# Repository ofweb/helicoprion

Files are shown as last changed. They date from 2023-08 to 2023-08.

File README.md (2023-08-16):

# Helicoprion Keyboard

The Helicoprion Keyboard is a 44-key diodeless, flippable, choc spaced, hotswap, aggressive column staggered, split keyboard powered by Pro Micro pin compatible board, eg a nice!nano or a KB2040.
It does not have battery support, but you can use a nice!nano wired if you want.

I made this after having build and attempted to use a sweep. Tha lack of dedicated modifier keys kept being a problem for me. The normal tucky thumb keys are hard to reach for me so I came up with this that I think feels better.
I don't expect this to by my last iteration on a keyboard so it is made to allow me to recycle the MCU and the switches in a next iteration.

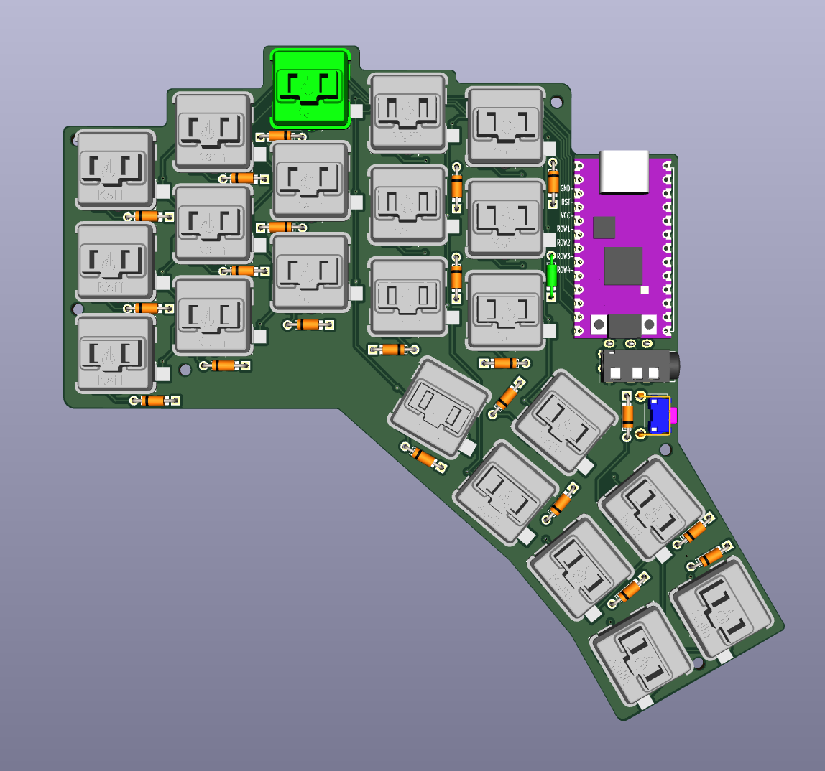
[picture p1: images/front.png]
left

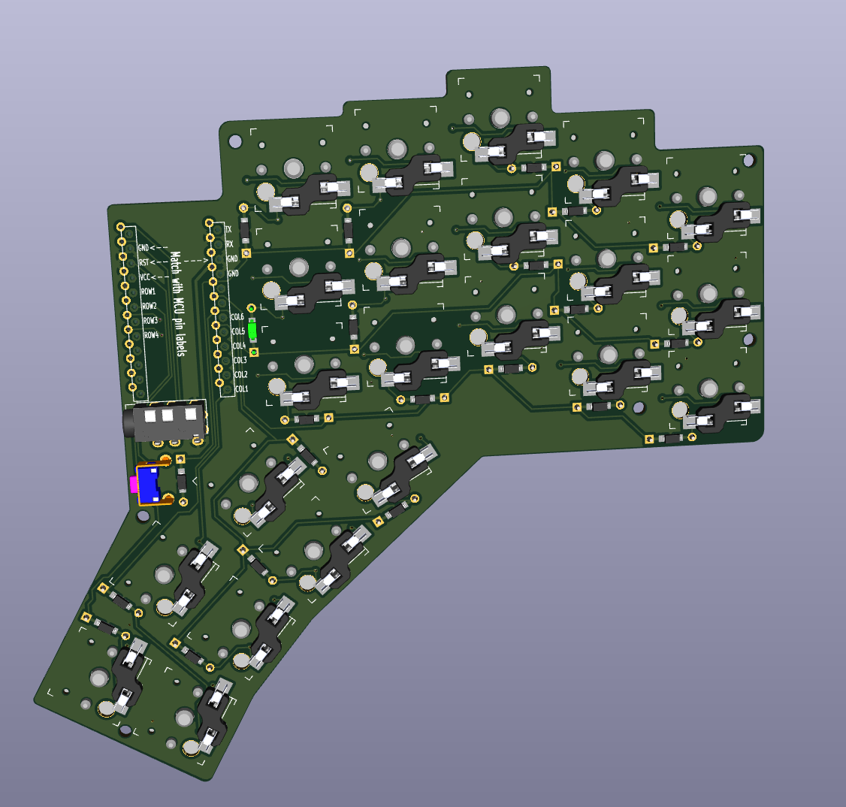
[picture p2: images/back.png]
right


# Testing
If you want to see if this is right for you you can start with printing a paper tester (TODO). If you have access to a 3d-printer you can print the step file(TODO) from the repo and add you switches, this should give you a better indication on if it is right.

# Inspiration

* [Sweep](https://github.com/davidphilipbarr/Sweep) The main inspiration is from the ferris sweep I started trying to used I needed more keys.
* [Hillside](https://github.com/mmccoyd/hillside) The very pretty promicro foot print and how to wire it.
* [Torn](https://github.com/rtitmuss/torn) For not be afraid of showing the components and that it can look very nice.

## Features

* Pro Micro MCU - Many options
* Sweep inspired layout - Ergonomic strong column staggering for short pinkies.
* Flippable PCBs - Cheaper to order the PCBs
* Hotswap low profile choc switches - Experiment with different key switches with the hotswap sockets.
* Very large thumb cluster - Let your thumb do more of the work.
* Both SMD and THT diodes - Pick if you want the easier to solder or the smaller diodes.

## Bill of Materials (BOM)

[Interactive](https://ofweb.github.io/helicoprion/)

Quantity | Item
--- | ---
2 | Helicoprion PCB
2 | Pro Micro pin compatable comtrollers
44 | Kailh choc v1 PG1350 switches
44 | Choc v1 keycaps
44 | Kahli hotswap sockets for choc v1 PG1350
44 | Diodes both through-hole (eg. 1N4148) and smd (SOD-123) are supported
2 | TRRS jack PJ-320A (not needed for nice!nano)
1 | 3.5mm TRRS cable (not needed for nice!nano)
4 | Pin headers (20 pin) or sockets
2 | Reset Button (optional) ALPS SKHLLCA010 or footprint compatible

# releases
## V1
### Errata: 
 - sw9 connect pin 1 (square) to MCU pin 20 (row1)
 - sw10 connect pin 1 (square) to MCU pin 19 (row2)
 - MCU pin 10 to (col3) to MCU pin 10 (col3). The inner most pin is connected the outer most is not and need to be if you are using it.

# schematic
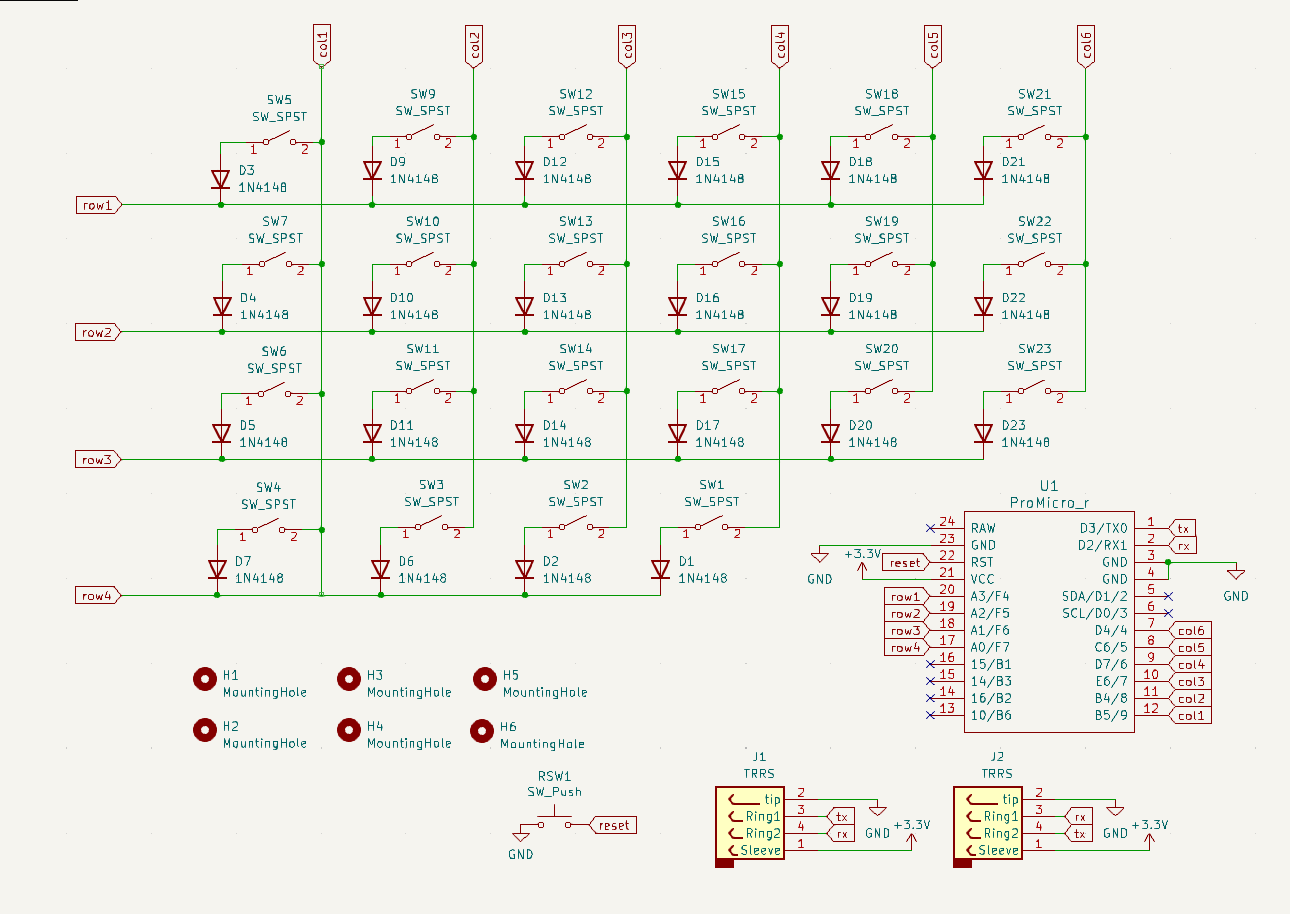
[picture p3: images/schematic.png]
schematic


## External footprints and symbols used

External symbols and footprints are not covered by the LICENSE in this repo.

* [Keebio-Parts.pretty](https://github.com/keebio/Keebio-Parts.pretty) is licensed under the MIT License.
* [keyswitches.pretty](https://github.com/daprice/keyswitches.pretty) is licensed under the Creative Commons Attribution-ShareAlike 4.0 International License.
* [Hillside](https://github.com/mmccoyd/hillside) is licensed under the MIT License.

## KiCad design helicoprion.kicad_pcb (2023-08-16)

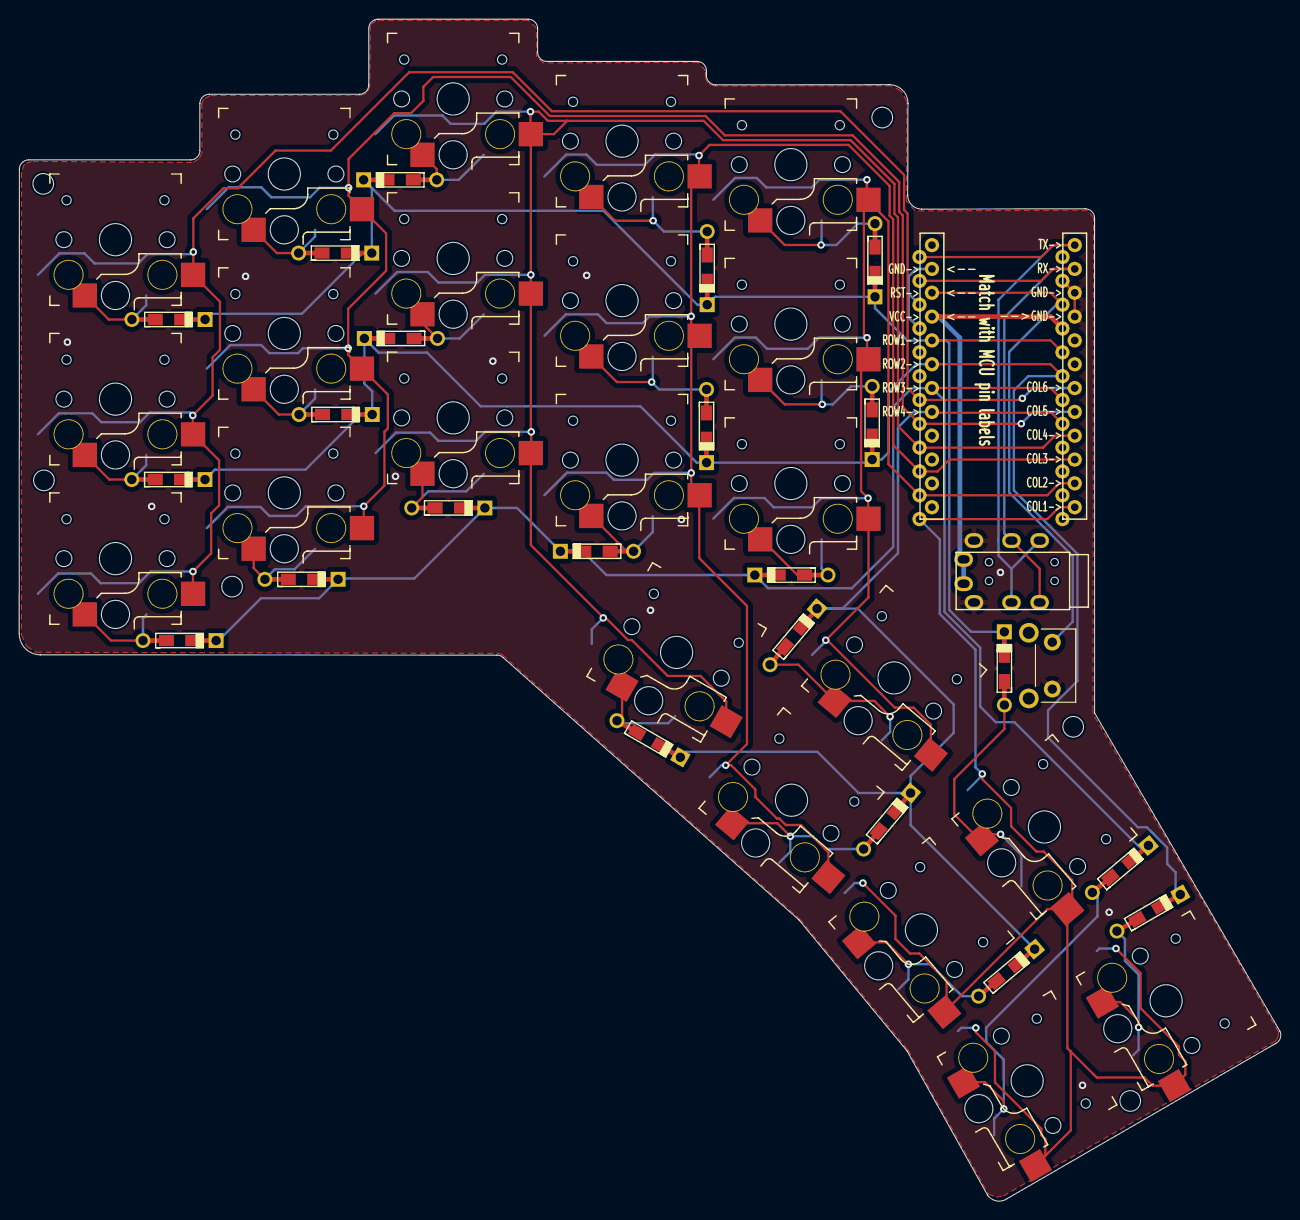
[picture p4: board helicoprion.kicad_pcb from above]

Board: 2 copper layers, 134.5 x 126.0 mm, 54 parts (1 on the bottom side), 37 nets.

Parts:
D1, D2, D3, D4, D5, D6, D7, D9, D10, D11, D12, D13, D14, D15, D16, D17, D18, D19, D20, D21, D22, D23: 1N4148; Diode-dual
H1, H2, H3, H4, H5, H6: MountingHole; MountingHole_2.2mm_M2
J1, J2: TRRS; TRRS-PJ-320A
RSW1: SW_Push; SW_SKHLLCA010
SW1, SW2, SW3, SW4, SW5, SW6, SW7, SW9, SW10, SW11, SW12, SW13, SW14, SW15, SW16, SW17, SW18, SW19, SW20, SW21, SW22, SW23: SW_SPST; Kailh_socket_PG1350_reversible
U1: ProMicro_r; ProMicro_v2

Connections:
+3.3V: J1.1 (Sleeve), J2.1 (Sleeve), U1.21 (VCC)
GND: J1.2 (tip), J2.2 (tip), RSW1.1, U1.3 (GND), U1.4 (GND), U1.23 (GND)
unnamed: D1.2 (A), SW1.1 (A)
unnamed: D2.2 (A), SW2.1 (A)
unnamed: D3.2 (A), SW5.1 (A)
unnamed: D4.2 (A), SW7.1 (A)
unnamed: D5.2 (A), SW6.1 (A)
unnamed: D6.2 (A), SW3.1 (A)
unnamed: D7.2 (A), SW4.1 (A)
unnamed: D9.2 (A), SW9.1 (A)
unnamed: D10.2 (A), SW10.1 (A)
unnamed: D11.2 (A), SW11.1 (A)
unnamed: D12.2 (A), SW12.1 (A)
unnamed: D13.2 (A), SW13.1 (A)
unnamed: D14.2 (A), SW14.1 (A)
unnamed: D15.2 (A), SW15.1 (A)
unnamed: D16.2 (A), SW16.1 (A)
unnamed: D17.2 (A), SW17.1 (A)
unnamed: D18.2 (A), SW18.1 (A)
unnamed: D19.2 (A), SW19.1 (A)
unnamed: D20.2 (A), SW20.1 (A)
unnamed: D21.2 (A), SW21.1 (A)
unnamed: D22.2 (A), SW22.1 (A)
unnamed: D23.2 (A), SW23.1 (A)
col1: SW4.2 (B), SW5.2 (B), SW6.2 (B), SW7.2 (B), U1.12 (B5/9)
col2: SW3.2 (B), SW9.2 (B), SW10.2 (B), SW11.2 (B), U1.11 (B4/8)
col3: SW2.2 (B), SW12.2 (B), SW13.2 (B), SW14.2 (B), U1.10 (E6/7)
col4: SW1.2 (B), SW15.2 (B), SW16.2 (B), SW17.2 (B), U1.9 (D7/6)
col5: SW18.2 (B), SW19.2 (B), SW20.2 (B), U1.8 (C6/5)
col6: SW21.2 (B), SW22.2 (B), SW23.2 (B), U1.7 (D4/4)
reset: RSW1.2, U1.22 (RST)
row1: D3.1 (K), D9.1 (K), D12.1 (K), D15.1 (K), D18.1 (K), D21.1 (K), U1.20 (A3/F4)
row2: D4.1 (K), D10.1 (K), D13.1 (K), D16.1 (K), D19.1 (K), D22.1 (K), U1.19 (A2/F5)
row3: D5.1 (K), D11.1 (K), D14.1 (K), D17.1 (K), D20.1 (K), D23.1 (K), U1.18 (A1/F6)
row4: D1.1 (K), D2.1 (K), D6.1 (K), D7.1 (K), U1.17 (A0/F7)
rx: J1.4 (Ring2), J2.3 (Ring1), U1.2 (D2/RX1)
tx: J1.3 (Ring1), J2.4 (Ring2), U1.1 (D3/TX0)

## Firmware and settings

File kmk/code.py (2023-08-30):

import board

from kmk.kmk_keyboard import KMKKeyboard
from kmk.keys import KC
from kmk.scanners import DiodeOrientation
from kmk.modules.split import Split, SplitType
from kmk.modules.layers import Layers
from kmk.modules.capsword import CapsWord
from kmk.extensions.media_keys import MediaKeys



keyboard = KMKKeyboard()
keyboard.debug_enabled = True
keyboard.modules.append(Layers())
keyboard.extensions.append(MediaKeys())

caps_word=CapsWord()
keyboard.modules.append(caps_word)

# https://github.com/KMKfw/kmk_firmware/blob/master/docs/en/split_keyboards.md
# https://github.com/KMKfw/kmk_firmware/blob/master/boards/kyria/main.py
split = Split(  
    split_side=None,
    split_type=SplitType.UART,
    uart_flip=False,
    data_pin=board.D1,
    data_pin2=board.D0,
    use_pio=False,
    split_target_left=True
)
keyboard.modules.append(split)

keyboard.col_pins = (board.D4, board.D5, board.D6, board.D7, board.D8, board.D9)
keyboard.row_pins = (board.A3, board.A2, board.A1, board.A0)
keyboard.diode_orientation = DiodeOrientation.COL2ROW


# +--+--+--+--+--+                    +--+--+--+--+--+
# |00|01|02|03|04|                    |28|27|26|25|24|
# +--+--+--+--+--+                    +--+--+--+--+--+
# |06|07|08|09|10|                    |34|33|32|31|30| 
# +--+--+--+--+--+                    +--+--+--+--+--+
# |12|13|14|15|16|                    |40|39|38|37|36|
# +--+--+--+--+--+--+--+--+  +--+--+--+--+--+--+--+--+
#             +--|22|05|11|  |35|29|46|--+            
#             |20+--+--+--+  +--+--+--+44|            
#             +--|21|23|17|  |41|47|45|--+            
#                +--+--+--+  +--+--+--+               

# [
#     00, 01, 02, 03, 04, 05, 29, 28, 27, 26, 25, 24,
#     06, 07, 08, 09, 10, 11, 35, 34, 33, 32, 31, 30,
#     12, 13, 14, 15, 16, 17, 41, 40, 39, 38, 37, 36,
#     --, --, 20, 21, 22, 23, 47, 46, 45, 44, --, --,
# ]


keyboard.keymap = [
# +--+--+--+--+--+                    +--+--+--+--+--+
# | Q| W| F| P| B|                    | J| L| U| Y| ⌫|
# +--+--+--+--+--+                    +--+--+--+--+--+
# | A| R| S| T| G|                    | M| N| E| I| O| 
# +--+--+--+--+--+                    +--+--+--+--+--+
# | Z| X| C| D| V|                    | K| H| Æ| Ø| Å|
# +--+--+--+--+--+--+--+--+  +--+--+--+--+--+--+--+--+
#             +--| ⇥| ⇧| .|  | ;| ⎈|CW|--+            
#             |L1+--+--+--+  +--+--+--+L2|           
#             +--| ⎵| ⌥| ,|  | :| ⌘| ↵|--+            
#                +--+--+--+  +--+--+--+         
    [
        KC.Q,   KC.W,   KC.F,       KC.P,   KC.B,       KC.LSFT,    KC.RCTRL,  KC.J,    KC.L,       KC.U,               KC.Y,               KC.BSPC,
        KC.A,   KC.R,   KC.S,       KC.T,   KC.G,       KC.DOT,     KC.SCLN,   KC.M,    KC.N,       KC.E,               KC.I,               KC.O,
        KC.Z,   KC.X,   KC.C,       KC.D,   KC.V,       KC.COMM,    KC.COLN,   KC.K,    KC.H,       KC.LALT(KC.QUOT),   KC.LALT(KC.O),      KC.LALT(KC.A),
        KC.NO,  KC.NO,  KC.MO(1),   KC.SPC, KC.TAB,     KC.LALT,    KC.RCMD,   KC.CW,   KC.ENT,     KC.MO(2),           KC.NO,              KC.NO,
    ],
# +--+--+--+--+--+                    +--+--+--+--+---+
# | @| _| \| "| +|                    | >| )| }| ]|DEL|
# +--+--+--+--+--+                    +--+--+--+--+---+
# | #| -| /| '| =|                    | <| (| {| [| ^ | 
# +--+--+--+--+--+                    +--+--+--+--+---+
# | $| ~| || `| ?|                    | !| %|  | &| * |
# +--+--+--+--+--+--+--+--+  +--+--+--+--+--+--+--+---+
#             +--| ⇥| ⇧| .|  | ;| ⎈|CW|--+            
#             |L1+--+--+--+  +--+--+--+L2|           
#             +--| ⎵| ⌥| ,|  | :| ⌘| ↵|--+            
#                +--+--+--+  +--+--+--+      
    [
        KC.AT,      KC.UNDS,    KC.BSLS,     KC.DQUO,     KC.PLUS,      KC.TRNS,    KC.TRNS,   KC.RABK,    KC.RPRN,       KC.RCBR,     KC.RBRC,      KC.DEL,
        KC.HASH,    KC.MINS,    KC.SLSH,     KC.QUOT,     KC.EQL,       KC.TRNS,    KC.TRNS,   KC.LABK,    KC.LPRN,       KC.LCBR,     KC.LBRC,      KC.CIRC,
        KC.DLR,     KC.TILD,    KC.PIPE,     KC.GRV,      KC.QUES,      KC.TRNS,    KC.TRNS,   KC.EXLM,    KC.PERC,       KC.NO,       KC.AMPR,      KC.ASTR,
        KC.NO,      KC.NO,      KC.TRNS,     KC.TRNS,     KC.TRNS,      KC.TRNS,    KC.TRNS,   KC.TRNS,    KC.TRNS,       KC.TRNS,     KC.NO,        KC.NO,
    ],
# +---+--+--+--+--+                    +---+---+---+---+---+
# |del|  | 7| 8| 9|                    |F11|F12| VU|MUT| VD|
# +---+--+--+--+--+                    +---+---+---+---+---+
# | → | ↑| 4| 5| 6|                    | F6| F7| F8| F9|F10| 
# +---+--+--+--+--+                    +---+---+---+---+---+
# | ← | ↓| 1| 2| 3|                    | F1| F2| F3| F4| F5|
# +---+--+--+--+--+--+--+--+  +--+--+--+---+---+---+---+---+
#             +--| ⇥| ⇧| .|  | ;| ⎈|CW|--+            
#             |L1+--+--+--+  +--+--+--+L2|           
#             +--| ⎵| ⌥| ,|  | :| ⌘| ↵|--+            
#                +--+--+--+  +--+--+--+        
    [
        KC.GESC,     KC.NO,    KC.N7,     KC.N8,     KC.N9,      KC.TRNS,    KC.TRNS,   KC.F11,       KC.F12,      KC.VOLU,   KC.MUTE,    KC.VOLD,
        KC.RIGHT,   KC.UP,    KC.N4,     KC.N5,     KC.N6,      KC.TRNS,    KC.TRNS,   KC.F6,        KC.F7,       KC.F8,     KC.F9,      KC.F10,
        KC.LEFT,    KC.DOWN,  KC.N1,     KC.N2,     KC.N3,      KC.TRNS,    KC.TRNS,   KC.F1,        KC.F2,       KC.F3,     KC.F4,      KC.F5,
        KC.NO,      KC.NO,    KC.TRNS,   KC.TRNS,   KC.TRNS,    KC.TRNS,    KC.TRNS,   KC.TRNS,      KC.TRNS,     KC.TRNS,   KC.NO,      KC.NO,
    ]
]


if __name__ == '__main__':
    keyboard.go()

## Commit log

2023-04-19 add images and fix edge cut
    [windlass.kicad_pcb]
2023-04-20 rename kicad files
    [helicoprion.kicad_pcb, helicoprion.kicad_sch]
2023-04-20 added 3d models
    [helicoprion.kicad_pcb]
2023-04-27 finish layout
    [helicoprion.kicad_pcb, helicoprion.kicad_sch]
2023-04-27 addded gerber
    [helicoprion-B_Cu.gbl, helicoprion-B_Mask.gbs, helicoprion-B_Paste.gbp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]
2023-04-27 Add ground vias and gerber
    [helicoprion-B_Cu.gbl, helicoprion-B_Mask.gbs, helicoprion-B_Paste.gbp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]
2023-04-28 fix silkscreen for mcu
    [helicoprion.kicad_pcb]
2023-05-12 start of firmware and interactive bom
    [helicoprion.kicad_pcb, helicoprion.kicad_sch]
2023-05-12 add link to bom
2023-07-03 new gerber and ibom
    [helicoprion-B_Cu.gbl, helicoprion-B_Mask.gbs, helicoprion-B_Paste.gbp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]
2023-08-16 fix erata for v1 and get left side working
    [helicoprion.kicad_pcb]
2023-08-16 update readme, bom and 3d renders
2023-08-16 remove v1 gerber as it should not be ordered. move new ibom to root
    [helicoprion-B_Cu.gbl, helicoprion-B_Mask.gbs, helicoprion-B_Paste.gbp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]
